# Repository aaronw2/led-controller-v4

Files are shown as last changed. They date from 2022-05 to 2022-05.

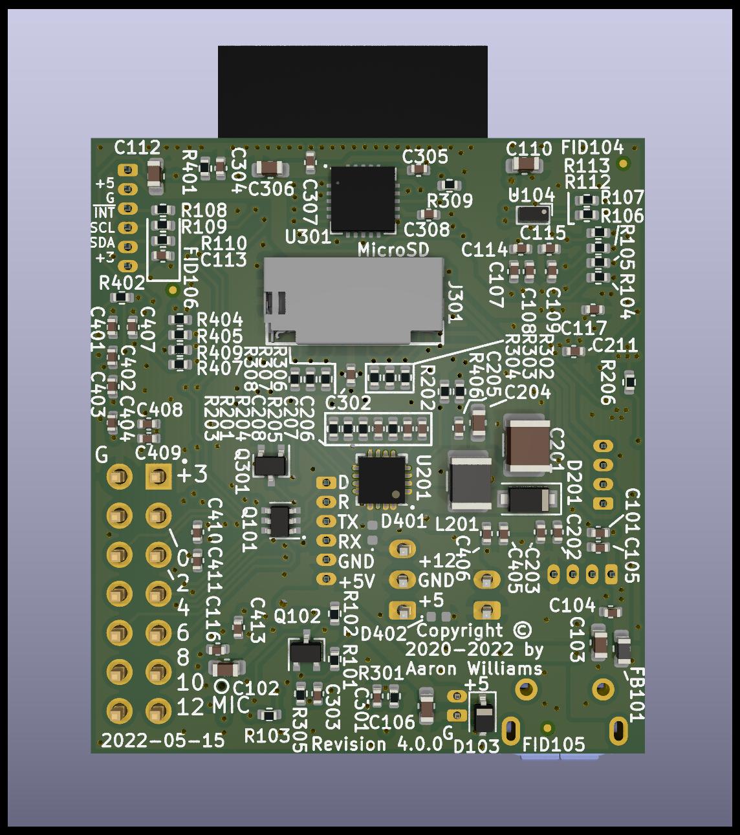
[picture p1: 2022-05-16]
led-controller-wrover32-back.jpg

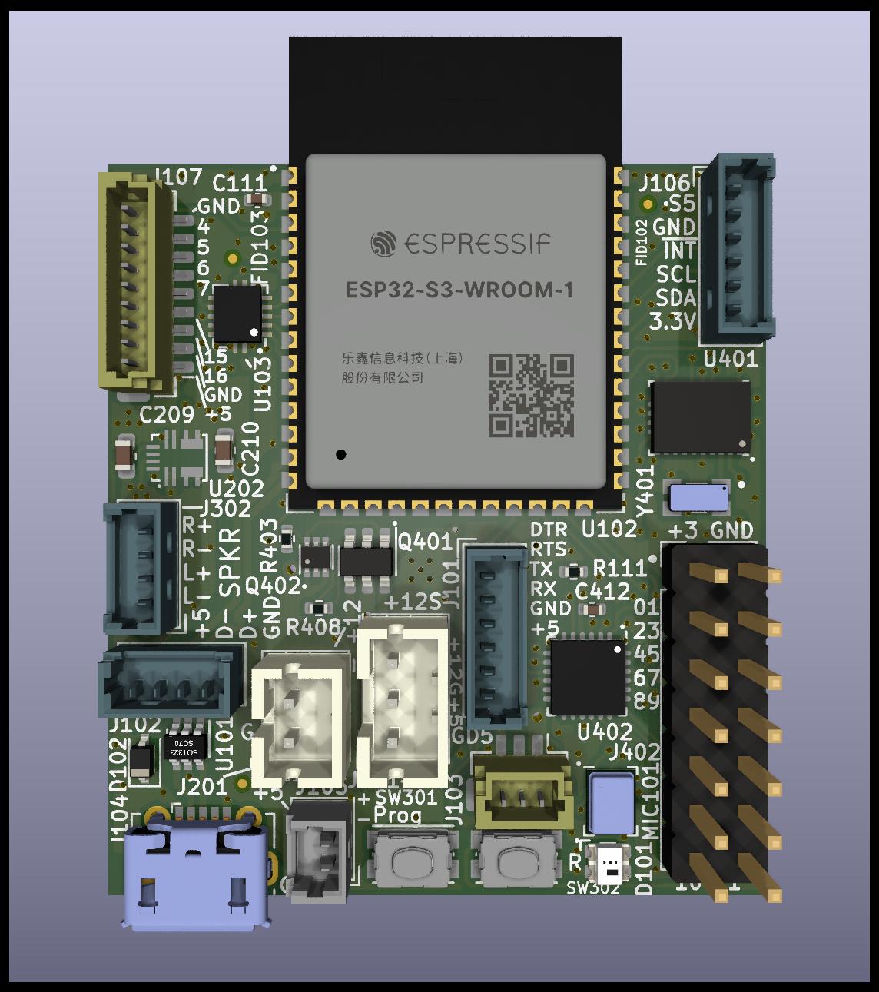
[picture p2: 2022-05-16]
led-controller-wrover32-front.jpg

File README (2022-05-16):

ESP32-Wrover I/Os

IO0: (/program), /INT
IO2: BNO085 reset
IO3: Fan PWM
IO4: 5V I/O J108 pin 8
IO5: 5V I/O J108 pin 7
IO6: 5V I/O J108 pin 6
IO7: 5V I/O J108 pin 5
IO8: I2S1 BCLK (stereo speaker J304)
IO9: Micro SD D1
IO10: Micro SD D0
IO11: Micro SD CLK
IO12: Micro SD CMD
IO13: Micro SD D3
IO14: Micro SD D2
IO15: 5v I/O J108 pin 4
IO16: 5v I/O J108 pin 3
IO17: I2S1 WSEL (stereo speaker J304)
IO18: I2S1 DOUT (stereo speaker J304)
IO19: USB D-
IO20: USB D+
IO21: Status LED, LED output to J103 pin 2
IO38: /INT2
IO39: M_BOOT_LOAD, BNO085 motion sensor
IO40: I2C SDA, J107 pin 5
IO41: I2C SCL, J107 pin 4
IO42: /INT3, J107 pin 3
IO45: I2S0 BCLK (Microphone)
IO46: 12V power supply enable high
IO47: I2S0 WSEL (Microphone)
IO48: I2S0 DIN (Microphone)
RXD0: Serial port RX
TXD0: Serial port TX
EN: /RESET

Bootstrap:

Boot mode:  IO0  IO46
SPI Boot    1    X
Download    0    0

VDD SPI voltage:
IO45: 0 = 3.3V, 1 = 1.8V

JTAG:
IO3:  0 = JTAG pins, 1 = USB Serial/JTAG

Reset:
The reset signal is driven by the reset button, Q101 via the serial
port RTS/DTR signals, and from the power good output of the 3.3V power supply.
The reset signal drives the reset inputs of the BNO085 motion controller,
the PCA9575 GPIO expander, and the ESP32 S3.  Note that IO2 can also reset
the BNO085 to support loading the bootloader from the ESP32.

Power:
All power is supplied at 5V from either J105, micro USB J104, or USB J102.
J105 is the preferred power source.  5V is converted to 3.3V by the
MPM3810GQB-33 module which provides up to 1.2A.  The power good signal from
this module drives the reset signal so the chip will not be brought out of
reset until after the 3.3V has stabilized.  The 12V supply can provide up to
500ma and by default is disabled until IO46 is pulled high.  IO46 is low by
default since it is used for bootstrapping.  This is separate from the fan
PWM which is cointrolled by IO3.

While the board has been configured to handle at least 2A of power at 5V,
this board is not designed to provide power to a significant number of LEDs
or devices.  It is expected that they will have their own power supply with
a common ground.

Fans:
This board provides two outputs for fans.  The first, J201, provides 12V
without PWM support whenever IO46 is pulled high.  Connector J401 provides
both 5V and 12V and both supplies are modulated or controlled by GPIO IO3
which must be pulled high.  IO3 controls both 5V and 12V simultaneously.
The fan outputs have diodes to protect against any back EMF.

I2C:
The I2C bus uses 2.2K pull-up resistors instead of the more traditional 4.7
or 10K.  This is due to the fact that the i2c bus can be exported off of the
board and having stronger pull-ups should provide better signal integrity.
There are three interrupt lines that are supported.  Internally, i2c is
used by the GPIO expander, the motion sensor, and the I2S stereo audio
amplifier.

5V signalling:
Six GPIOs pass through open-collector level shifters with pull-up resistors.
These may be used to drive NeoPixels or other 5V devices and are
bi-directional.  All 5V I/Os also have a 33 ohm resistor in series to help
reduce reflections.

Status LED:
A WS2812 compatible status LED is present and is driven by IO21.  The output
of this LED may be used to drive additional LEDs and is connected to J103.

USB:
The USB is connected to the ESP32 controller after passing through a protection
and USB termination chip U101.

Buttons:
Reset - Pulls the reset signal low
Prog - Pulls IO0 low to boot into programming mode.  Since IO0 is also the
INT signal it can be used to generate an interrupt at runtime.  Note that
INT is shared with the I2C GPIO expander.

I2C GPIO Expander:
A PCA9575HF provides 12 additional GPIO pins which may be configured for input
or output.  They can also be configured to generate an interrupt on the INT
signal (IO0).  The GPIO expander chip is also connected to the reset signal.

Motion Controller/Accelerometer:
A BNO085 9-axis accelerometer/gyroscope/compass/temperature sensor chip is
provided for tracking motion.  This chip performs all the necessary
calculations and offloads them from the ESP32.  It is connected via I2C and
INT2.  The boot loader pin is also connected to a GPIO pin.

I2C Addresses:
PCA9575: 0x20
BNO085 motion sensor: 0x29
SSM2518CPZ: 0x36

ESP32 GPIO pins by function:

I2C:
SCL: IO41
SDA: IO42
INT: IO0
INT2: IO38
INT3: IO42

Microphone:
I2S0_BCLK: IO45
I2S0_WSEL: IO47
I2S0_DIN:  IO48

Amplifier:
Power: IO1
I2S1_BCLK: IO8
I2S1_WSEL: IO17
I2S1_DOUT: IO18

Status LED:
IO21

MicroSD:
CLK: IO11
CMD: IO12
D0:  IO10
D1:  IO9
D2:  IO14
D3:  IO13

12V Enable:
EN: IO46

Fan PWM:
PWM: IO3

Motion Sensor:
M_BOOT_LOAD: IO39
Interrupt: INT2
Reset: Reset and IO2

GPIO Expander:
Interrupt: INT

5V I/O Pins:
IO4
IO5
IO6
IO7
IO15
IO16

Program: IO0, INT

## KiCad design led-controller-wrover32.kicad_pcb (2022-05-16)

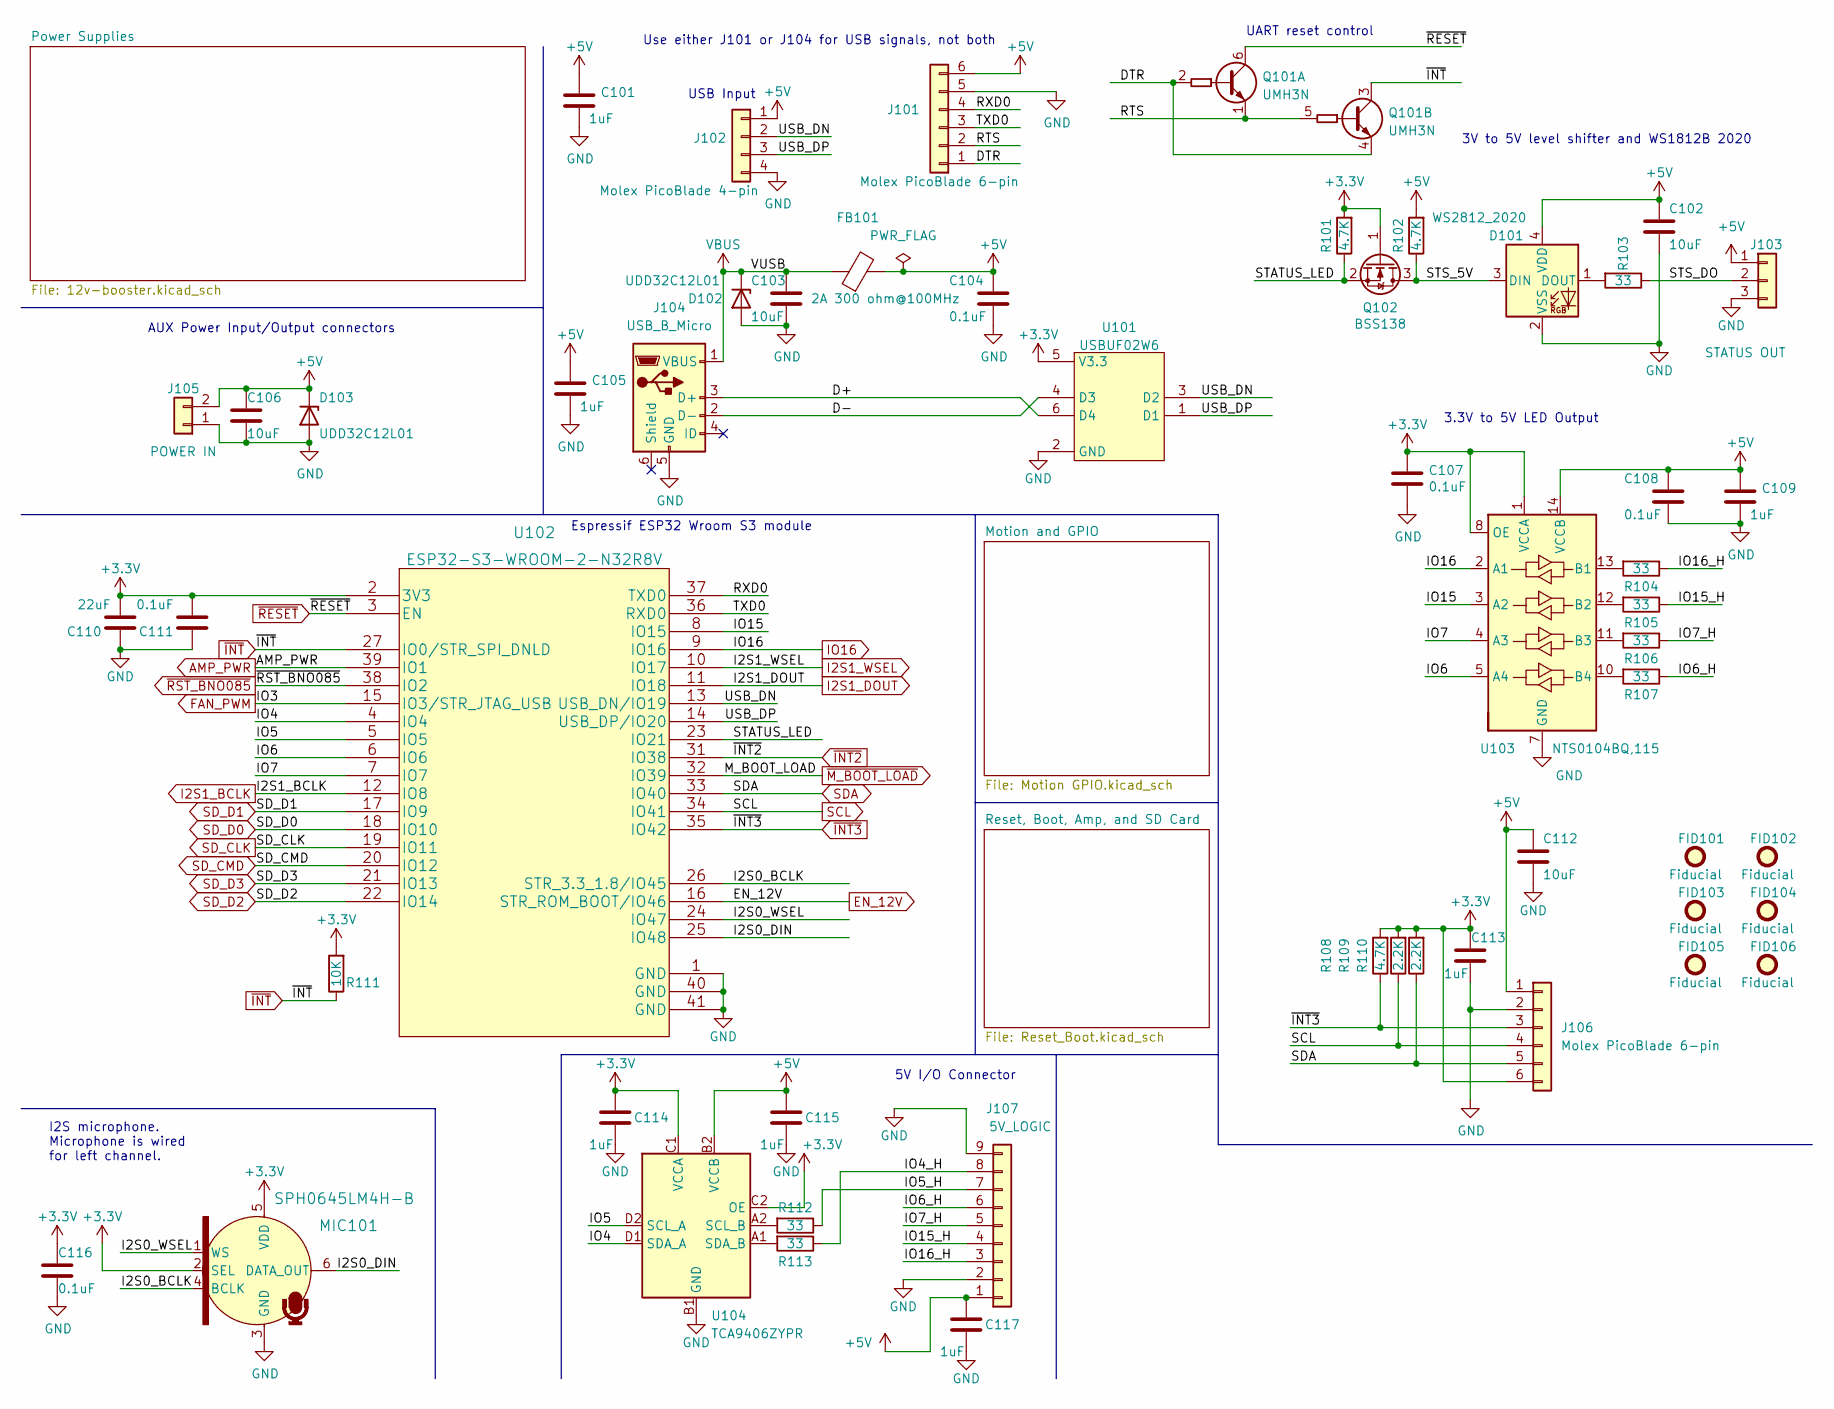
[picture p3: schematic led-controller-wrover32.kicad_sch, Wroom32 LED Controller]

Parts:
C101, C105, C109, C113, C114, C115, C117: 1uF; C_0402_1005Metric
C102, C103, C106, C112: 10uF; C_0603_1608Metric
C104, C107, C108, C111, C116: 0.1uF; C_0402_1005Metric
C110: 22uF; C_0603_1608Metric
D101: WS2812_2020; LED_WS2812_2020
D102, D103: UDD32C12L01; D_SOD-323
FB101: 2A 300 ohm@100MHz; L_0603_1608Metric; MPN MI0603L301R-10
FID101, FID102, FID103, FID104, FID105, FID106: Fiducial; Fiducial_0.5mm_Mask1mm
J101, J106: Molex PicoBlade 6-pin; Molex_PicoBlade_53047-0610_1x06_P1.25mm_Vertical
J102: Molex PicoBlade 4-pin; Molex_PicoBlade_53047-0410_1x04_P1.25mm_Vertical; MPN 0530470410
J103: STATUS OUT; JST_SH_BM03B-SRSS-TB_1x03-1MP_P1.00mm_Vertical
J104: USB_B_Micro; USB_Micro-B_Molex-105017-0001
J105: POWER IN; Molex_PicoBlade_53047-0210_1x02_P1.25mm_Vertical; MPN 0530470210
J107: 5V_LOGIC; JST_SH_BM09B-SRSS-TB_1x09-1MP_P1.00mm_Vertical
MIC101: SPH0645LM4H-B; Knowles_LGA-6_3.5x2.65mm; MPN SPH0645LM4H-B; Digi-Key_PN 423-1405-1-ND
Q101: UMH3N; SOT-363_SC-70-6
Q102: BSS138; SOT-323_SC-70; MPN BSS138
R101, R102, R108: 4.7K; R_0402_1005Metric
R103, R104, R105, R106, R107, R112, R113: 33; R_0402_1005Metric
R109, R110: 2.2K; R_0402_1005Metric
R111: 10K; R_0402_1005Metric; Tolerance 5%
U101: USBUF02W6; SOT-323-6L
U102: ESP32-S3-WROOM-2-N32R8V
U103: NTS0104BQ,115; SOT-762-1; MPN NTS0104BQ,115
U104: TCA9406ZYPR; Texas_DSBGA-8_0.9x1.9mm_Layout2x4_P0.5mm

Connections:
+3V3: C107.1, C110.1, C111.1, C113.1, C114.1, C116.1, J106.6, MIC101.2 (SEL), MIC101.5 (VDD), Q102.1 (G), R101.2, R108.2, R109.2, R110.2, R111.2, U101.5 (V3.3), U102.2 (3V3), U103.1 (VCCA), U103.8 (OE), U104.C1 (VCCA), U104.C2 (OE); also elsewhere on the board
+5V: C101.1, C102.1, C104.1, C105.1, C106.1, C108.1, C109.1, C112.1, C115.1, C117.1, D101.4 (VDD), D103.1 (K), FB101.2, J101.6, J102.1, J103.1, J105.2, J106.1, J107.1, R102.2, U103.14 (VCCB), U104.B2 (VCCB); also elsewhere on the board
/D+: J104.3 (D+), U101.6 (D4)
/D-: J104.2 (D-), U101.4 (D3)
/DTR: J101.1, Q101.2 (B1), Q101.4 (E2)
/I2S0_BCLK: MIC101.4 (BCLK), U102.26 (STR_3.3_1.8/IO45)
/I2S0_DIN: MIC101.6 (DATA_OUT), U102.25 (IO48)
/I2S0_WSEL: MIC101.1 (WS), U102.24 (IO47)
/IO4: U102.4 (IO4), U104.D1 (SDA_A)
/IO4_H: J107.8, R113.1
/IO5: U102.5 (IO5), U104.D2 (SCL_A)
/IO5_H: J107.7, R112.1
/IO6: U102.6 (IO6), U103.5 (A4)
/IO6_H: J107.6, R107.1
/IO7: U102.7 (IO7), U103.4 (A3)
/IO7_H: J107.5, R106.1
/IO15: U102.8 (IO15), U103.3 (A2)
/IO15_H: J107.4, R105.1
/IO16_H: J107.3, R104.1
/RTS: J101.2, Q101.1 (E1), Q101.5 (B2)
/RXD0: J101.4, U102.37 (TXD0)
/STATUS_LED: Q102.2 (S), R101.1, U102.23 (IO21)
/STS_5V: D101.3 (DIN), Q102.3 (D), R102.1
/STS_DO: J103.2, R103.1
/TXD0: J101.3, U102.36 (RXD0)
/USB_DN: J102.2, U101.3 (D2), U102.13 (USB_DN/IO19)
/USB_DP: J102.3, U101.1 (D1), U102.14 (USB_DP/IO20)
AMP_PWR: U102.39 (IO1); also elsewhere on the board
EN_12V: U102.16 (STR_ROM_BOOT/IO46); also elsewhere on the board
FAN_PWM: U102.15 (IO3/STR_JTAG_USB); also elsewhere on the board
GND: C101.2, C102.2, C103.2, C104.2, C105.2, C106.2, C107.2, C108.2, C109.2, C110.2, C111.2, C112.2, C113.2, C114.2, C115.2, C116.2, C117.2, D101.2 (VSS), D102.2 (A), D103.2 (A), J101.5, J102.4, J103.3, J104.5 (GND), J105.1, J106.2, J107.2, J107.9, MIC101.3 (GND), U101.2 (GND), U102.1 (GND), U102.40 (GND), U102.41 (GND), U103.7 (GND), U103.15 (GND), U104.B1 (GND); also elsewhere on the board
I2S1_BCLK: U102.12 (IO8); also elsewhere on the board
I2S1_DOUT: U102.11 (IO18); also elsewhere on the board
I2S1_WSEL: U102.10 (IO17); also elsewhere on the board
IO16: U102.9 (IO16), U103.2 (A1)
unnamed: D101.1 (DOUT), R103.2
unnamed: R104.2, U103.13 (B1)
unnamed: R105.2, U103.12 (B2)
unnamed: R106.2, U103.11 (B3)
unnamed: R107.2, U103.10 (B4)
unnamed: R112.2, U104.A2 (SCL_B)
unnamed: R113.2, U104.A1 (SDA_B)
SCL: J106.4, R109.1, U102.34 (IO41); also elsewhere on the board
SDA: J106.5, R110.1, U102.33 (IO40); also elsewhere on the board
SD_CLK: U102.19 (IO11); also elsewhere on the board
SD_CMD: U102.20 (IO12); also elsewhere on the board
SD_D0: U102.18 (IO10); also elsewhere on the board
SD_D1: U102.17 (IO9); also elsewhere on the board
SD_D2: U102.22 (IO14); also elsewhere on the board
SD_D3: U102.21 (IO13); also elsewhere on the board
VBUS: C103.1, D102.1 (K), FB101.1, J104.1 (VBUS)
~INT2: U102.31 (IO38); also elsewhere on the board
~INT3: J106.3, R108.1, U102.35 (IO42)
~INT: Q101.3 (C2), R111.1, U102.27 (IO0/STR_SPI_DNLD); also elsewhere on the board
~M_BOOT_LOAD: U102.32 (IO39); also elsewhere on the board
~RESET: Q101.6 (C1), U102.3 (EN); also elsewhere on the board
~RST_BNO085: U102.38 (IO2); also elsewhere on the board

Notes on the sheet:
Espressif ESP32 Wroom S3 module
3V to 5V level shifter and WS1812B 2020
I2S microphone. Microphone is wired for left channel.
3.3V to 5V LED Output
Use either J101 or J104 for USB signals, not both
5V I/O Connector
AUX Power Input/Output connectors
UART reset control
USB Input

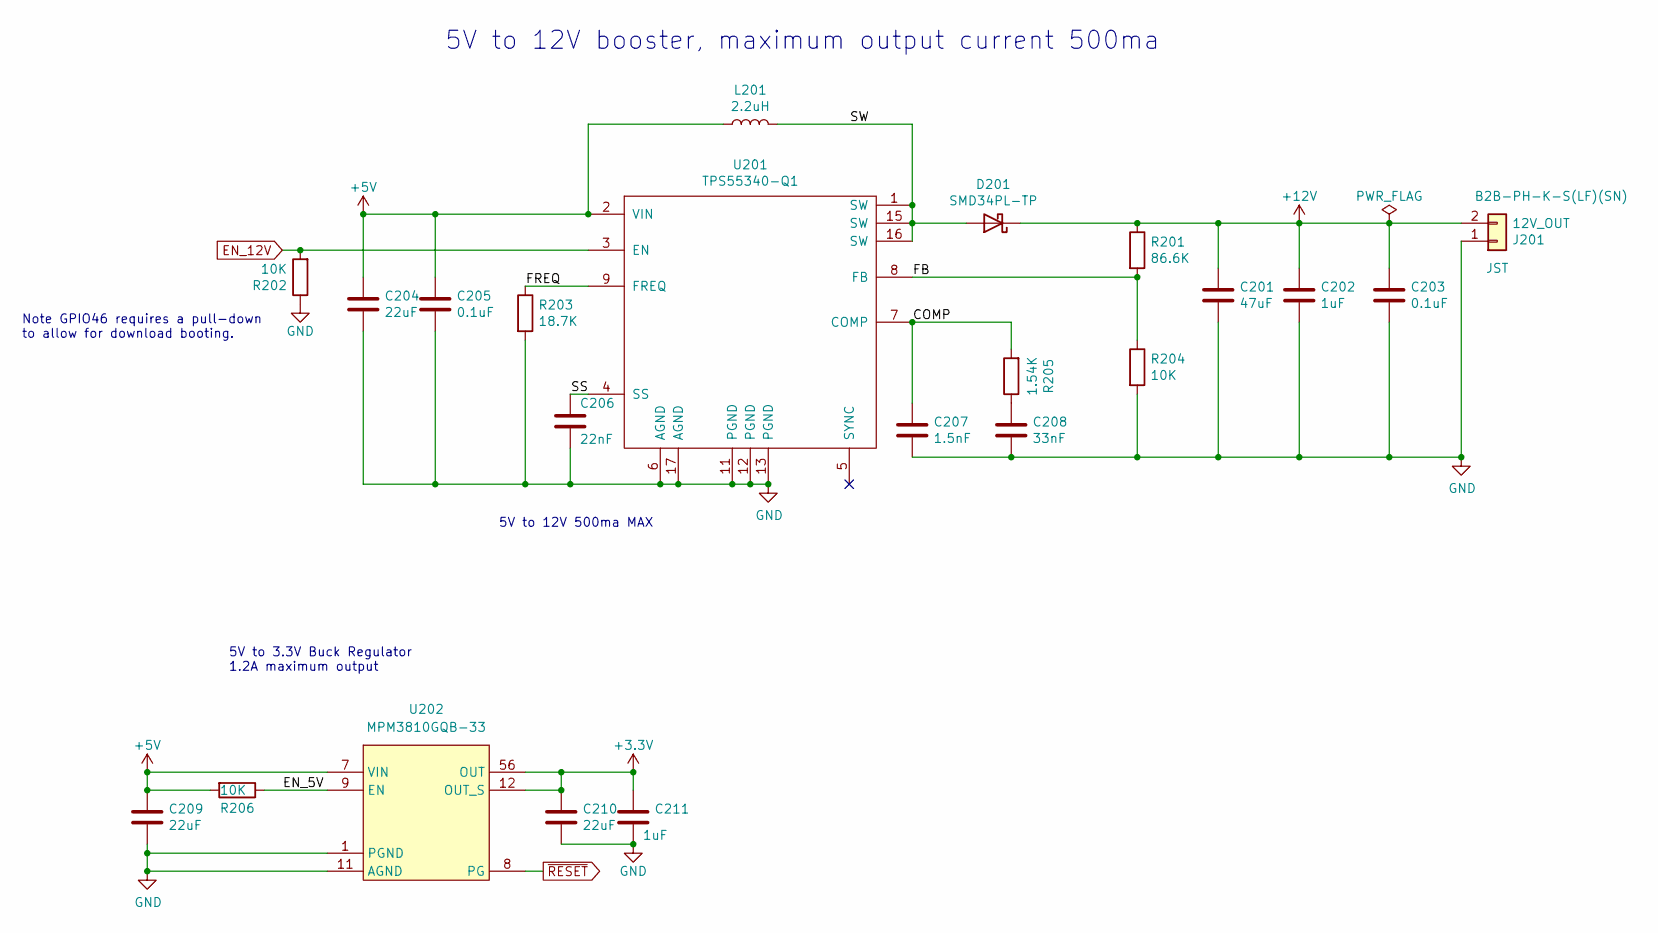
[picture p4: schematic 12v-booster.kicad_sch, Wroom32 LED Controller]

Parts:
C201: 47uF; C_1210_3225Metric; MPN CL32A476KOJNNNE
C202, C211: 1uF; C_0402_1005Metric
C203, C205: 0.1uF; C_0402_1005Metric
C204, C209, C210: 22uF; C_0603_1608Metric; MPN CL10A226MO7JZNC
C206: 22nF; C_0402_1005Metric
C207: 1.5nF; C_0402_1005Metric
C208: 33nF; C_0402_1005Metric
D201: SMD34PL-TP; D_SOD-123F; MPN SMD34PL-TP
J201: 12V_OUT; JST_PH_B2B-PH-K_1x02_P2.00mm_Vertical; MPN B2B-PH-K-S(LF)(SN)
L201: 2.2uH; L_1210_3225Metric; MPN DFE322520FD-2R2M=P2
R201: 86.6K; R_0402_1005Metric
R202, R204, R206: 10K; R_0402_1005Metric
R203: 18.7K; R_0402_1005Metric; MPN RC0603FR-0718K7L
R205: 1.54K; R_0402_1005Metric
U201: TPS55340-Q1; QFN-16-1EP_3x3mm_P0.5mm_EP2.7x2.7mm_ThermalVias; MPN TPS55340RTER
U202: MPM3810GQB-33; Monolithic_QFN-12-2.5x3.0mm_P0.4mm

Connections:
+3V3: C210.1, C211.1, U202.12 (OUT_S), U202.56 (OUT); also elsewhere on the board
+5V: C204.1, C205.1, C209.1, L201.1, R206.2, U201.2 (VIN), U202.7 (VIN); also elsewhere on the board
+12V: C201.1, C202.1, C203.1, D201.1 (K), J201.2, R201.1; also elsewhere on the board
/Power Supplies/COMP: C207.1, R205.2, U201.7 (COMP)
/Power Supplies/EN_5V: R206.1, U202.9 (EN)
/Power Supplies/FB: R201.2, R204.1, U201.8 (FB)
/Power Supplies/FREQ: R203.1, U201.9 (FREQ)
/Power Supplies/SS: C206.1, U201.4 (SS)
/Power Supplies/SW: D201.2 (A), L201.2, U201.1 (SW), U201.15 (SW), U201.16 (SW)
EN_12V: R202.2, U201.3 (EN); also elsewhere on the board
GND: C201.2, C202.2, C203.2, C204.2, C205.2, C206.2, C207.2, C208.2, C209.2, C210.2, C211.2, J201.1, R202.1, R203.2, R204.2, U201.6 (AGND), U201.11 (PGND), U201.12 (PGND), U201.13 (PGND), U201.17 (AGND), U202.1 (PGND), U202.2 (PGND), U202.11 (AGND); also elsewhere on the board
unnamed: C208.1, R205.1
~RESET: U202.8 (PG); also elsewhere on the board

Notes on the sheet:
Note GPIO46 requires a pull-down to allow for download booting.
5V to 3.3V Buck Regulator 1.2A maximum output
5V to 12V 500ma MAX
5V to 12V booster, maximum output current 500ma

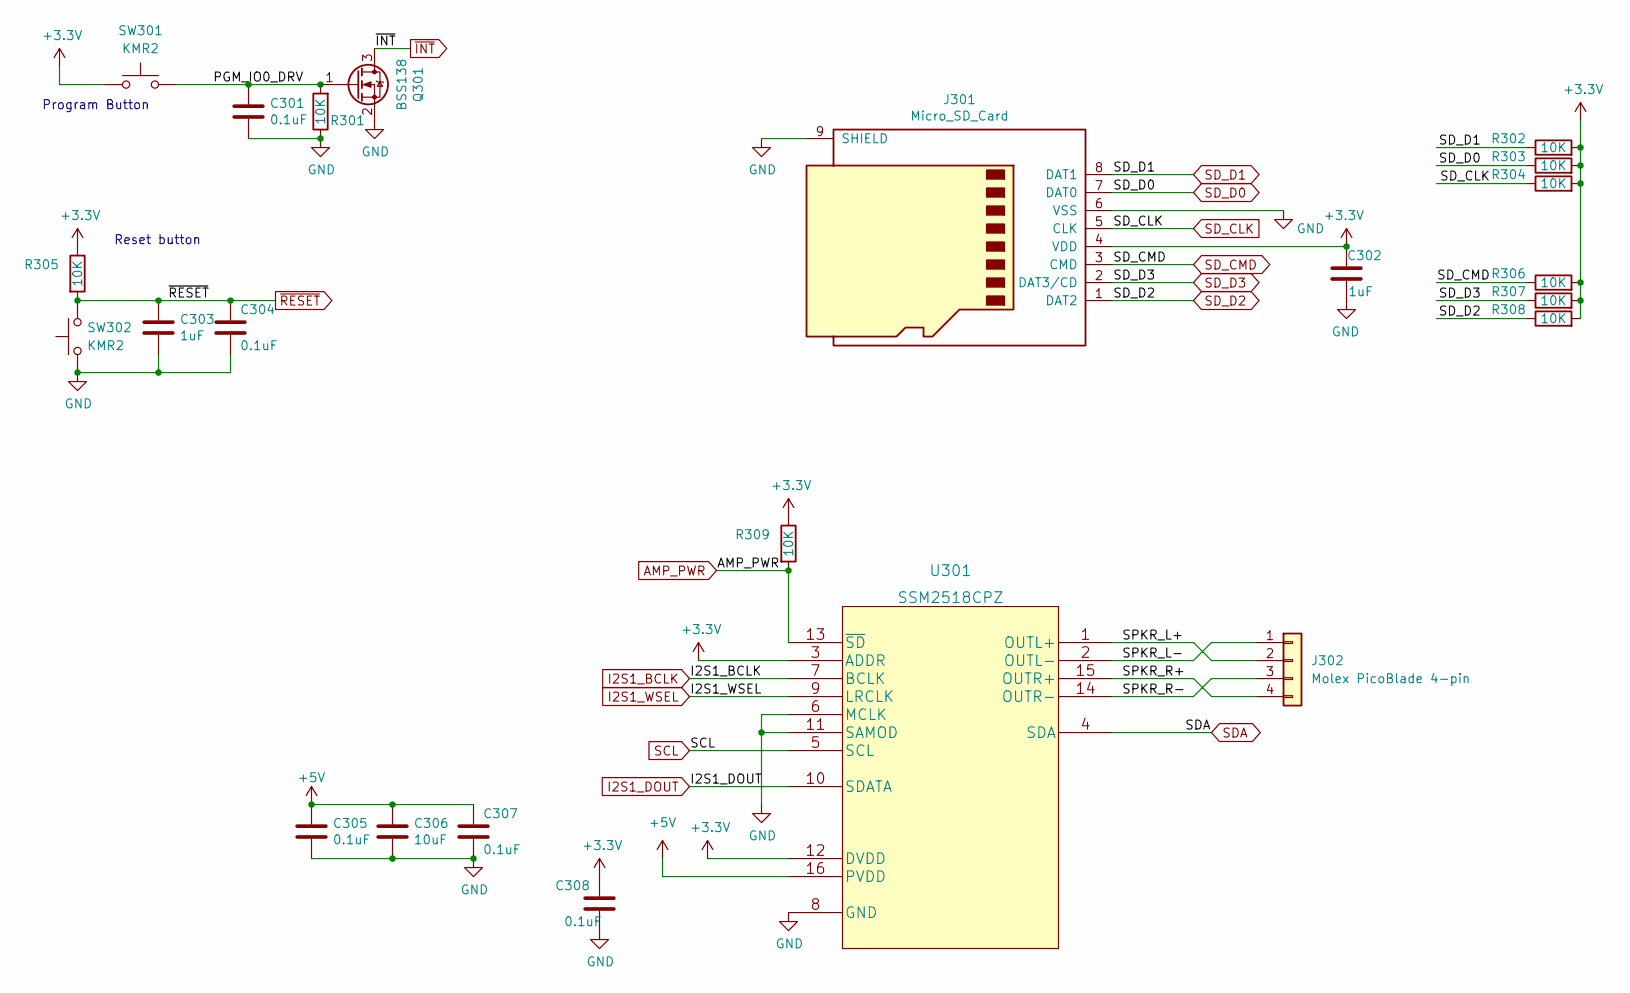
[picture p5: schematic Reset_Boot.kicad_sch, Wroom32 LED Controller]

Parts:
C301, C304, C305, C307, C308: 0.1uF; C_0402_1005Metric
C302, C303: 1uF; C_0402_1005Metric
C306: 10uF; C_0603_1608Metric
J301: Micro_SD_Card; microSD_HC_Molex_047571-0001; MPN 0475710001
J302: Molex PicoBlade 4-pin; Molex_PicoBlade_53047-0410_1x04_P1.25mm_Vertical
Q301: BSS138; SOT-323_SC-70; MPN BSS138
R301, R302, R303, R304, R305, R306, R307, R308, R309: 10K; R_0402_1005Metric; Tolerance 5%
SW301, SW302: KMR2; SW_Push_1P1T_NO_CK_KMR2
U301: SSM2518CPZ; LFCSP-20-1EP_4x4mm_P0.5mm_EP2.6x2.6mm

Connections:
+3V3: C302.1, C308.1, J301.4 (VDD), R302.2, R303.2, R304.2, R305.1, R306.2, R307.2, R308.2, R309.1, SW301.1, U301.3 (ADDR), U301.12 (DVDD); also elsewhere on the board
+5V: C305.1, C306.1, C307.1, U301.16 (PVDD), U301.20 (PVDD); also elsewhere on the board
/Reset, Boot, Amp, and SD Card/PGM_IO0_DRV: C301.1, Q301.1 (G), R301.2, SW301.2
/Reset, Boot, Amp, and SD Card/SPKR_L+: J302.2, U301.1 (OUTL+)
/Reset, Boot, Amp, and SD Card/SPKR_L-: J302.1, U301.2 (OUTL-)
/Reset, Boot, Amp, and SD Card/SPKR_R+: J302.4, U301.15 (OUTR+)
/Reset, Boot, Amp, and SD Card/SPKR_R-: J302.3, U301.14 (OUTR-)
AMP_PWR: R309.2, U301.13 (~SD); also elsewhere on the board
GND: C301.2, C302.2, C303.2, C304.2, C305.2, C306.2, C307.2, C308.2, J301.6 (VSS), J301.9 (SHIELD), Q301.2 (S), R301.1, SW302.1, U301.6 (MCLK), U301.8 (GND), U301.11 (SAMOD), U301.17 (GND), U301.18 (GND), U301.19 (GND), U301.21 (GND); also elsewhere on the board
I2S1_BCLK: U301.7 (BCLK); also elsewhere on the board
I2S1_DOUT: U301.10 (SDATA); also elsewhere on the board
I2S1_WSEL: U301.9 (LRCLK); also elsewhere on the board
SCL: U301.5 (SCL); also elsewhere on the board
SDA: U301.4 (SDA); also elsewhere on the board
SD_CLK: J301.5 (CLK), R304.1; also elsewhere on the board
SD_CMD: J301.3 (CMD), R306.1; also elsewhere on the board
SD_D0: J301.7 (DAT0), R303.1; also elsewhere on the board
SD_D1: J301.8 (DAT1), R302.1; also elsewhere on the board
SD_D2: J301.1 (DAT2), R308.1; also elsewhere on the board
SD_D3: J301.2 (DAT3/CD), R307.1; also elsewhere on the board
~INT: Q301.3 (D); also elsewhere on the board
~RESET: C303.1, C304.1, R305.2, SW302.2; also elsewhere on the board

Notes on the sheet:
Program Button
Reset button

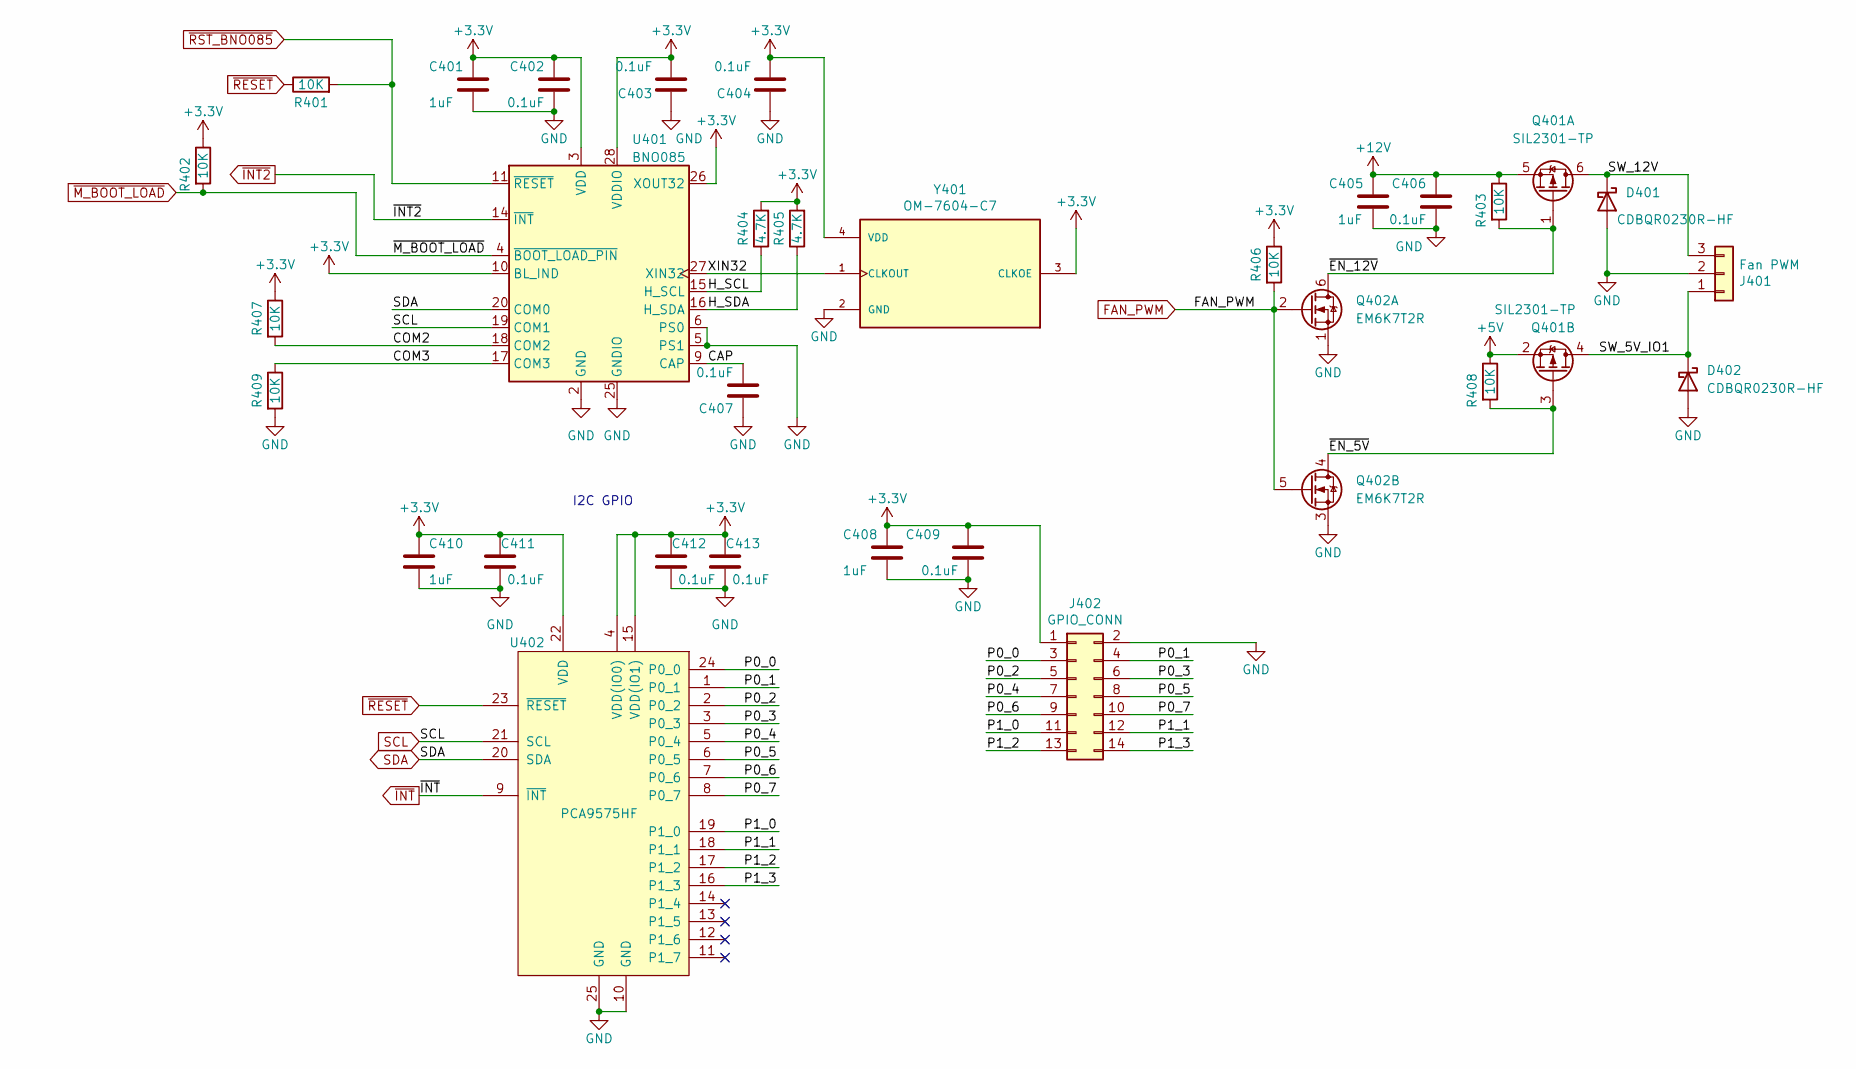
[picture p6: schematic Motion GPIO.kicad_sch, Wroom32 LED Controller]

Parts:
C401, C405, C408, C410: 1uF; C_0402_1005Metric
C402, C403, C404, C406, C407, C409, C411, C412, C413: 0.1uF; C_0402_1005Metric
D401, D402: CDBQR0230R-HF; D_0402_1005Metric; MPN CDBQR0230R-HF
J401: Fan PWM; JST_PH_B3B-PH-K_1x03_P2.00mm_Vertical
J402: GPIO_CONN; PinHeader_2x07_P2.54mm_Vertical
Q401: SIL2301-TP; SOT-23-6
Q402: EM6K7T2R; SOT-563
R401, R402, R403, R406, R407, R408, R409: 10K; R_0402_1005Metric; Tolerance 5%
R404, R405: 4.7K; R_0402_1005Metric
U401: BNO085; LGA-28_5.2x3.8mm_P0.5mm; MPN BNO085
U402: PCA9575HF; HWQFN-24_EP_4x4_Pitch0.5mm
Y401: OM-7604-C7; OSC_OM-7604-C7; PARTREV 4.2/06.2019

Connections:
+3V3: C401.1, C402.1, C403.1, C404.1, C408.1, C409.1, C410.1, C411.1, C412.1, C413.1, J402.1, R402.1, R404.2, R405.2, R406.1, R407.1, U401.3 (VDD), U401.10 (BL_IND), U401.26 (XOUT32), U401.28 (VDDIO), U402.4 (VDD(IO0)), U402.15 (VDD(IO1)), U402.22 (VDD), Y401.3 (CLKOE), Y401.4 (VDD); also elsewhere on the board
+5V: Q401.2 (S), R408.1; also elsewhere on the board
+12V: C405.1, C406.1, Q401.5 (S), R403.1; also elsewhere on the board
/Motion and GPIO/CAP: C407.1, U401.9 (CAP)
/Motion and GPIO/COM2: R407.2, U401.18 (COM2)
/Motion and GPIO/COM3: R409.1, U401.17 (COM3)
/Motion and GPIO/H_SCL: R404.1, U401.15 (H_SCL)
/Motion and GPIO/H_SDA: R405.1, U401.16 (H_SDA)
/Motion and GPIO/P0_0: J402.3, U402.24 (P0_0)
/Motion and GPIO/P0_1: J402.4, U402.1 (P0_1)
/Motion and GPIO/P0_2: J402.5, U402.2 (P0_2)
/Motion and GPIO/P0_3: J402.6, U402.3 (P0_3)
/Motion and GPIO/P0_4: J402.7, U402.5 (P0_4)
/Motion and GPIO/P0_5: J402.8, U402.6 (P0_5)
/Motion and GPIO/P0_6: J402.9, U402.7 (P0_6)
/Motion and GPIO/P0_7: J402.10, U402.8 (P0_7)
/Motion and GPIO/P1_0: J402.11, U402.19 (P1_0)
/Motion and GPIO/P1_1: J402.12, U402.18 (P1_1)
/Motion and GPIO/P1_2: J402.13, U402.17 (P1_2)
/Motion and GPIO/P1_3: J402.14, U402.16 (P1_3)
/Motion and GPIO/SW_5V_IO1: D402.1 (K), J401.1, Q401.4 (D)
/Motion and GPIO/SW_12V: D401.1 (K), J401.3, Q401.6 (D)
/Motion and GPIO/XIN32: U401.27 (XIN32), Y401.1 (CLKOUT)
/Motion and GPIO/~EN_5V: Q401.3 (G), Q402.4 (D), R408.2
/Motion and GPIO/~EN_12V: Q401.1 (G), Q402.6 (D), R403.2
FAN_PWM: Q402.2 (G), Q402.5 (G), R406.2; also elsewhere on the board
GND: C401.2, C402.2, C403.2, C404.2, C405.2, C406.2, C407.2, C408.2, C409.2, C410.2, C411.2, C412.2, C413.2, D401.2 (A), D402.2 (A), J401.2, J402.2, Q402.1 (S), Q402.3 (S), R409.2, U401.2 (GND), U401.5 (PS1), U401.6 (PS0), U401.25 (GNDIO), U402.10 (GND), U402.25 (GND), Y401.2 (GND); also elsewhere on the board
SCL: U401.19 (COM1), U402.21 (SCL); also elsewhere on the board
SDA: U401.20 (COM0), U402.20 (SDA); also elsewhere on the board
~INT2: U401.14 (~INT); also elsewhere on the board
~INT: U402.9 (~INT); also elsewhere on the board
~M_BOOT_LOAD: R402.2, U401.4 (~BOOT_LOAD_PIN); also elsewhere on the board
~RESET: R401.1, U402.23 (~RESET); also elsewhere on the board
~RST_BNO085: R401.2, U401.11 (~RESET); also elsewhere on the board

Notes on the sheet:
I2C GPIO

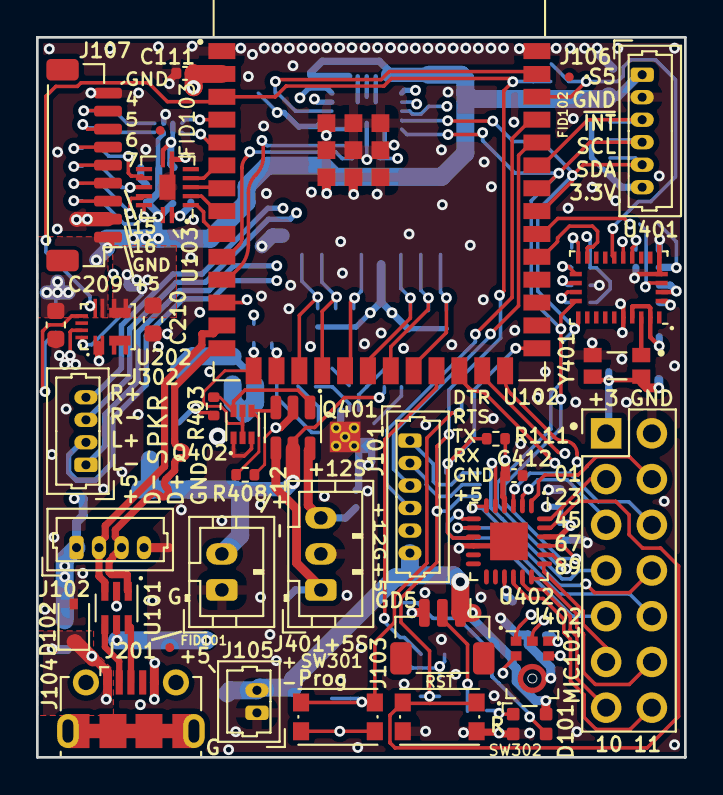
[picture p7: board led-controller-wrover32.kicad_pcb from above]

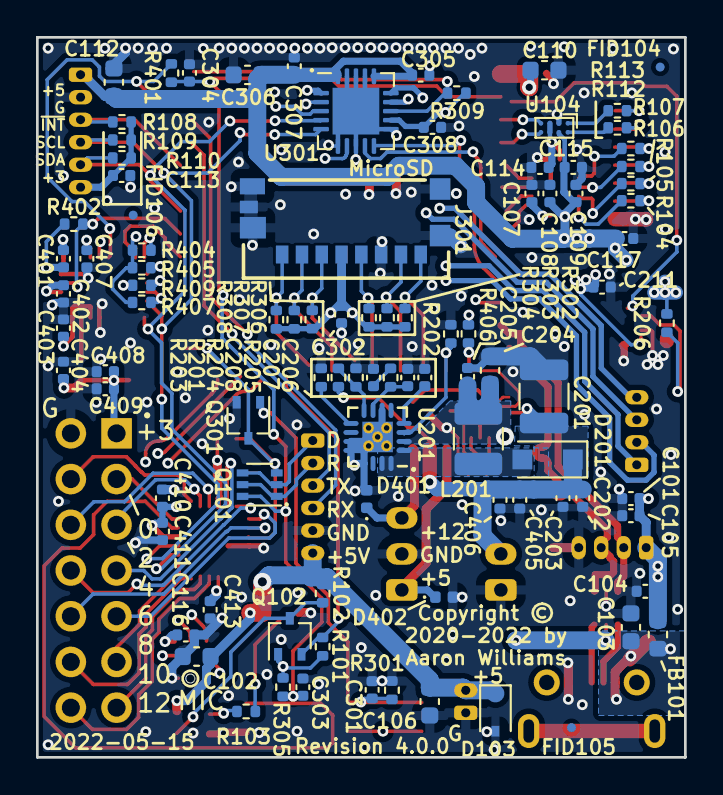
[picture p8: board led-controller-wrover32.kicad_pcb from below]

Board: 4 copper layers, 36.0 x 40.0 mm, 130 parts (95 on the bottom side), 92 nets.

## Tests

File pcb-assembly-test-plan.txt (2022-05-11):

Requirements:
1. Windows or Linux PC
2. A working micro USB cable
3. Putty on Windows or Minicom on Linux

1. Plug in Micro USB cable to Micro USB connector and into a PC
2. Measure voltage at J7. It should measure a little under 12V
3. Measure voltage between pins 1 and 5 on J8. It should measure 3.3V
4. The device should show up as a USB to serial device with a CP2104 USB to UART.
5. Open a terminal application, i.e. Putty on Windows or Minicom on Linux
6. Set the baud rate to 115200
7. Press SW1. A message should be displayed. The error message is expected.

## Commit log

2022-05-15 More updates
    - Changed obsolete unidirectional level shifter to open-collector level shifter
    - Replaced BSS138 level shifters with dedicated level shifter
    - Changed all 5V I/O pins to have 33 ohm resistor in series
    - Changed a few capacitors
    - Cleanup tracks, vias, silkscreen, etc.
    [12v-booster.kicad_sch, Motion GPIO.kicad_sch, Reset_Boot.kicad_sch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]
2022-05-15 Added BOM
2022-05-15 Multiple updates
    - Changed input current limiter to ferrite bead
    - Added pull-up for BNO085 boot mode
    - Minor layout changes
    [12v-booster.kicad_sch, Motion GPIO.kicad_sch, Reset_Boot.kicad_sch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]
2022-05-16 More updates
    - Removed 5V switch
    - Added manual reset control of BNO085 to support booting remotely
    - More minor cleanups
    - Added jpeg renderings
    [Motion GPIO.kicad_sch, Reset_Boot.kicad_sch, led-controller-wrover32.kicad_pcb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]

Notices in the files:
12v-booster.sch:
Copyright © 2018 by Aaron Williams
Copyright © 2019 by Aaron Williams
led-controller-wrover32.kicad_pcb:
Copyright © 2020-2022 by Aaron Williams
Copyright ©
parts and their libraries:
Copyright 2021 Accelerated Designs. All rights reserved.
